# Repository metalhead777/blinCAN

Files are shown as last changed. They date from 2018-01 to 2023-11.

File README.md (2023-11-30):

# blinCAN
A 24 channel LED driver module with CAN bus interface and Arduino-compatible microcontroller. 

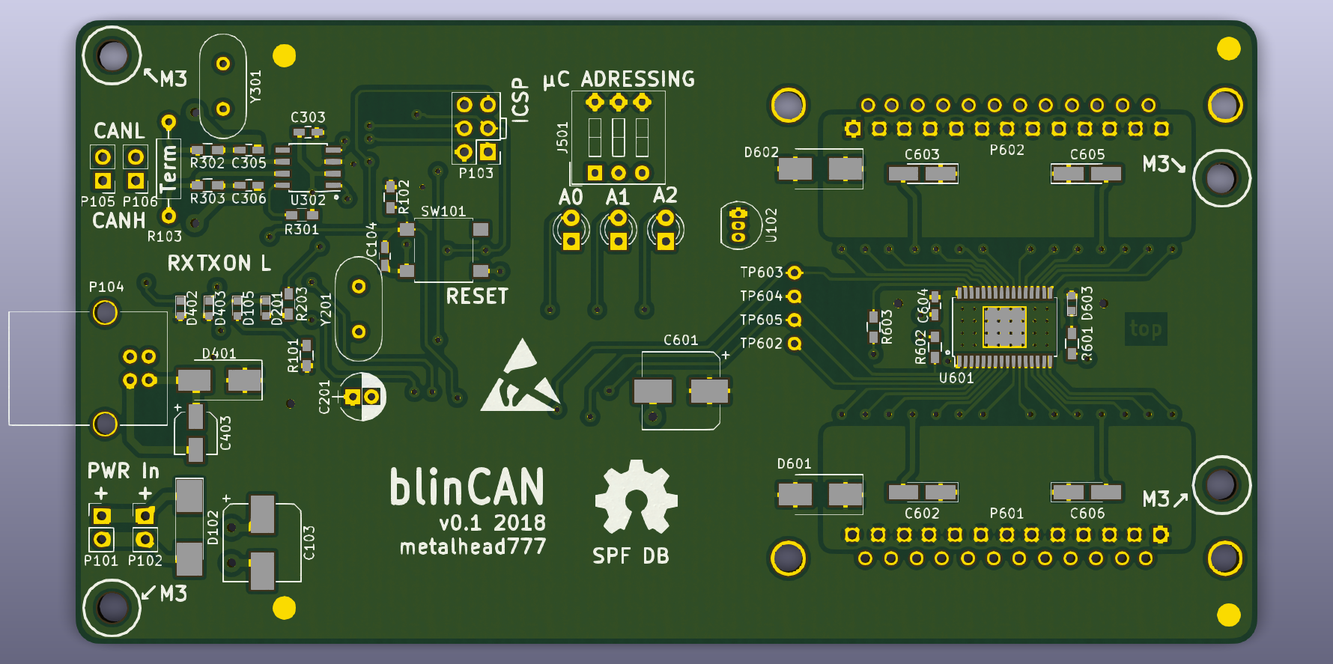
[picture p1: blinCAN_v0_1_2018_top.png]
blinCAN v0.1 2018 top

*blinCAN v0.1 2018 top*

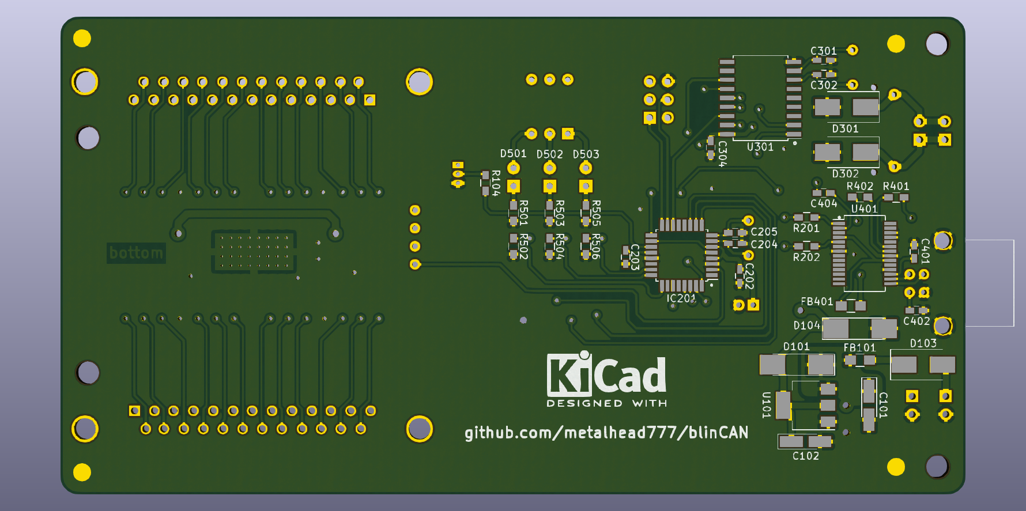
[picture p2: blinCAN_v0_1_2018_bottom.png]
blinCAN v0.1 2018 bottom

*blinCAN v0.1 2018 bottom*

## Function description

The blinCAN is based on a multi-channel power LED driver module developed for the [Desert Eyes project](http://deserteyes.net/). 
It is matched to a small-scale construction prototype dome, which served to test construction and lighting patterns for the full-scale dome. 

This module is built around a TLC5947 PWM LED driver IC, which is connected to an ATmega328 microcontroller. 
For communication, a MCP2551 CAN transceiver and a MCP2515 CAN controller with SPI interface to the microcontroller are utilized. 
A FT232R USB to UART interface has been added to allow programming via USB, once a bootloader is flashed onto the microcontroller. 
For ambient air temperature sensing, a LM35 temperature sensor has been placed near the LED driver IC. 
A DIP switch is used to set a hardware-level address on each device, which also gets indicated by corresponding LEDs.
For easier connection of an already wired LED harness, 25-pin SUB-D connectors are used on the output. 

On the small-scale construction prototype dome, a Raspberry Pi with a CAN bus HAT was used as a host to centrally generate and send lighting patterns to six blinCAN modules via the CAN bus. 
Each blinCAN module had a unique address within the CAN bus, and every LED on the dome was purposely connected to a predefined module output. 
This way, every LED on the dome's shell was distinctly addressable in 3D space. 
An underlying look-up-table in the host's software was used to map each pattern lighting point to an LED. 

### Current stage of development
Currently the blinCAN is in early development state in version 0.1. 
This means, that the hardware is tested and working on a small prototype scale production. 
Long-term testing (temperature, vibration, EMI) has not been performed yet. 
In this state the blinCAN is fit to be used for embedded systems and small-scale lighting projects. 
Any large-scale production is not encouraged, since additional optimization in the hardware layout needs to be done for that. 

A few prototypes have been built and successfully tested prior to releasing this repository. 

### Device commissioning description

#### Device connection

#### Device power requirements

### Device programming

After assembly, the device can only be programmed using an ICSP in-circuit-programmer.
The connector with the reference **P103** serves as ICSP header.
The square pad is ICSP Pin 1 (MISO).

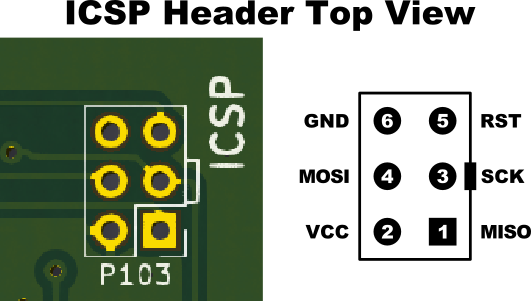
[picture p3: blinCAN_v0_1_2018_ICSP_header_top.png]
P103 ICSP header pin connection


*P103 ICSP header pin connection*

The blinCAN firmware can be flashed directly to the ATmega328P-AU using an In-Series Programmer (ISP).
The reset-button needs to be pressed during microcontroller flashing

For editing the blinCAN firmware or testing any other Arduino-compatible code, the Arduino bootlader needs to be flashed first to the ATmega328P-AU used for the blinCAN.
A tutorial on flashing the Arduino bootloader can be found [here](https://www.arduino.cc/en/tutorial/arduinoISP).
Use the following settings under "Tools" in the Arduino IDE, if you use another Arduino as a flashing device (ISP):

| Parameter | Value |
| --- |:---:|
| Board | "Arduino Nano" |
| Processor | "ATmega328P" |

After flashing the Arduino bootloader, any further programming can be done using the USB type B connector (**P104**) on the blinCAN.

#### Windows

#### Linux

#### MacOS

#### List of successfully tested programming adaptors

### Device communication reference

#### Internal

#### External

#### Addressing scheme

## Currently known bugs and issues
- Reset-button needs to be pressed during microcontroller flashing
- The TLC5947 has a thermal pad, which makes it the only component not solderable by purely using a soldering iron. Using a heatgun to heat the pad from the bottom side, applying solder and then placing the TLC5947 onto it has been done successfully for the prototypes.

## Planned future changes and improvements
- Add Bill of Materials (BOM) for all non-KiCAD users
- Clean up trace routing around TLC5947
- Increase number of hardware address bits
- Change LED output voltage to board input voltage instead of fix 5 V
- Add polyfuse for input overcurrent protection
- Add additional mounting points for Raspberry Pi (host system)

## Open source hardware and software used in this project

### KiCAD

- [KiCAD website](http://kicad.org/)
- Licensed under [GPL Version 3](https://www.gnu.org/licenses/gpl-3.0.html)

### Arduino nano Rev. 3

- [Arduino website](https://www.arduino.cc/)
- [Arduino nano Rev. 3 schematic](https://arduino.cc/en/uploads/Main/Arduino_Nano-Rev3.2-SCH.pdf)
- Licensed under [CC BY-SA 3.0](https://creativecommons.org/licenses/by-sa/3.0/)

### Arduino SparkFun CAN-Bus Shield Rev. 13

- [SparkFun website](https://www.sparkfun.com/)
- [SparkFun CAN-Bus Shield on GitHub](https://github.com/sparkfun/CAN-Bus_Shield/tree/V_H1.3_L5.0.0)
- [SparkFun CAN-Bus Shield Rev. 13 schematic](http://cdn.sparkfun.com/datasheets/Dev/Arduino/Shields/SparkFun_CAN-Bus_Shield_v13a.pdf)
- Licensed under [CC BY-SA 4.0](https://creativecommons.org/licenses/by-sa/4.0/)

## Active contributors to this project

### Firmware programmers

### Library programmers

## License information

This project is open source and licensed under [Creative Commons Attribution Share Alike 4.0](https://creativecommons.org/licenses/by-sa/4.0/).

Please refer to [License.md](License.md) for the full legal text. 
Thanks to [idleberg on GitHub](https://github.com/idleberg/Creative-Commons-Markdown) for the Markdown format. 

The project is distributed as-is. No warranty is given.

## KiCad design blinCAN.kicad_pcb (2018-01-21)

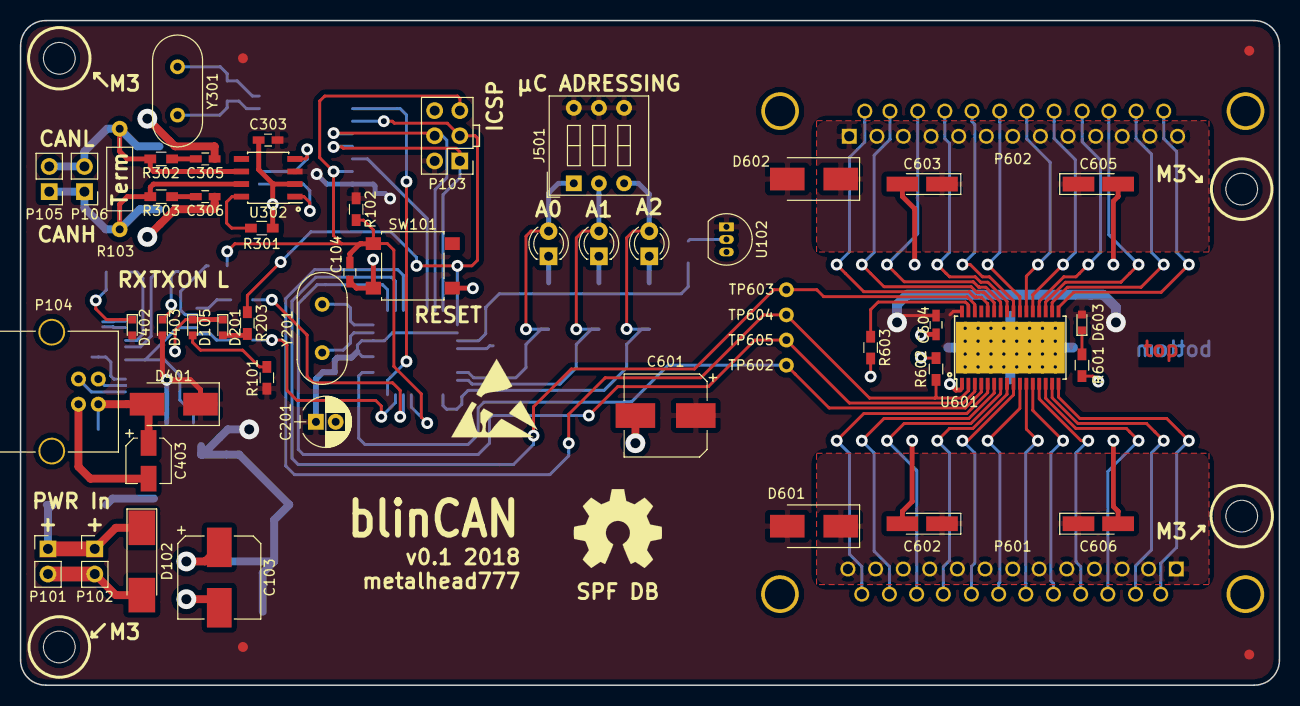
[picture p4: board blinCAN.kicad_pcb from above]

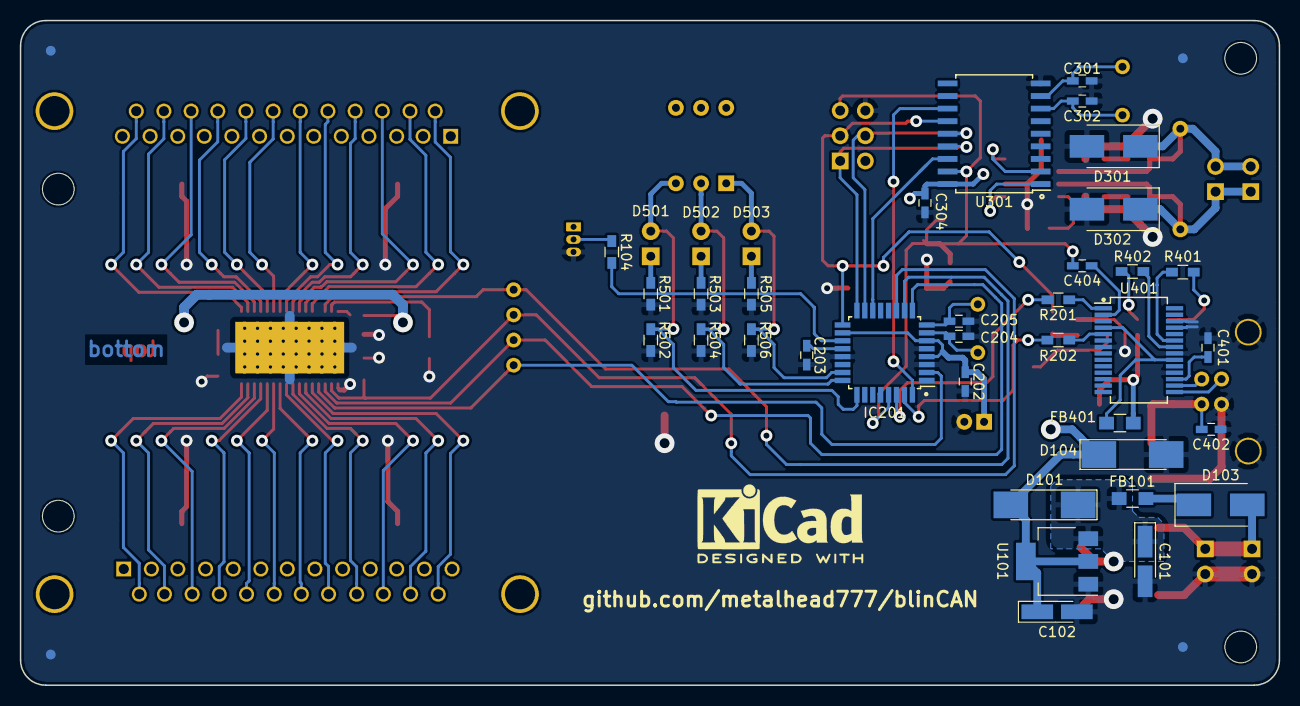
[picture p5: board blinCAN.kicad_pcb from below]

Board: 2 copper layers, 127.1 x 67.1 mm, 88 parts (34 on the bottom side), 79 nets.

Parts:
C101, C102, C602, C603, C605, C606: Tantal 10u/16V; CP_Tantalum_Case-A_EIA-3216-18_Hand
C103: 330u/25V; CP_Elec_8x10.5
C104, C202, C203, C303, C304, C401, C402, C404, C604: 100N; C_0603_HandSoldering
C201: 4.7u/16V; CP_Radial_D5.0mm_P2.00mm
C204, C205, C301, C302: 22P; C_0603_HandSoldering
C305, C306: 560p; C_0603_HandSoldering
C403: 4.7u/16V; CP_Elec_4x5.7
C601: 330u/16V; CP_Elec_8x10.5
D101, D102, D104: 1N 4001 SMD; D_MELF_Handsoldering
D103, D401, D601, D602: MBRS 240 SMD; D_SMB_Handsoldering
D105: LED Blue; LED_0603
D201: LED Orange; LED_0603
D301, D302: P6SMB 27A SMD; D_SMB_Handsoldering
D402: LED Red; LED_0603
D403, D603: LED Green; LED_0603
D501, D502, D503: LED Orange; LED_D3.0mm
FB101, FB401: EMI suppression Filter 30 Ohms; L_0805_HandSoldering
IC201: ATMEGA328P-AU; TQFP-32_7x7mm_Pitch0.8mm
J501: Conn_Address; SW_DIP_x3_W7.62mm_Slide
P101, P102: Conn_PWR_IN; Pin_Header_Straight_1x02_Pitch2.54mm
P103: CONN_ICSP; Pin_Header_Straight_2x03_Pitch2.54mm
P104: USB B; USB_B
P105, P106: Conn_CAN; Pin_Header_Straight_1x02_Pitch2.54mm
P601, P602: D-SUB 25; DB25FC
R101, R203, R401, R402: 330; R_0603_HandSoldering
R102, R104, R201, R202: 1k; R_0603_HandSoldering
R103: 120; R_Axial_DIN0207_L6.3mm_D2.5mm_P10.16mm_Horizontal
R301: 4k7; R_0603_HandSoldering
R302, R303: 100; R_0603_HandSoldering
R501, R503, R505: 130; R_0603_HandSoldering
R502, R504, R506: 10k; R_0603_HandSoldering
R601: 470; R_0603_HandSoldering
R602: 10K; R_0603_HandSoldering
R603: 3K3; R_0603_HandSoldering
SW101: Reset; SW_SPST_B3S-1000
TP602: TEST_DIN; Measurement_Point_Round-TH_Small
TP603: TEST_LAT; Measurement_Point_Round-TH_Small
TP604: TEST_OE; Measurement_Point_Round-TH_Small
TP605: TEST_CLK; Measurement_Point_Round-TH_Small
U101: LD1117S50TR_SOT223; SOT-223-3_TabPin2
U102: LM35DZ; TO-92_Inline_Narrow_Oval
U301: MCP2515-I/SO; SOIC-18W_7.5x11.6mm_Pitch1.27mm
U302: MCP2551-I/SN; SOIC-8_3.9x4.9mm_Pitch1.27mm
U401: FT232R; SSOP-28_5.3x10.2mm_Pitch0.65mm
U601: TLC5947; HTSSOP-32_6.1x11mm_Pitch0.65mm_ThermalPad
Y201, Y301: 16 MHz; Crystal_HC49-U_Vertical

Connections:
0-: P601.25, U601.5
1-: P601.24, U601.6
2-: P601.23, U601.7
3-: P601.22, U601.8
4-: P601.21, U601.9
5-: P601.20, U601.10
6-: P601.19, U601.11
7-: P601.18, U601.12
8-: P601.17, U601.13
9-: P601.16, U601.14
10-: P601.15, U601.15
11-: P601.14, U601.16
12-: P602.25, U601.17
13-: P602.24, U601.18
14-: P602.23, U601.19
15-: P602.22, U601.20
16-: P602.21, U601.21
17-: P602.20, U601.22
18-: P602.19, U601.23
19-: P602.18, U601.24
20-: P602.17, U601.25
21-: P602.16, U601.26
22-: P602.15, U601.27
23-: P602.14, U601.28
+5V: C102.1, C201.1, C202.1, C303.1, C304.1, C601.1, C604.2, D101.2, D104.1, D401.1, D402.2, D403.2, D601.2, D602.2, D603.2, FB401.2, IC201.4, IC201.6, IC201.18, J501.4, J501.5, J501.6, P103.2, R101.1, R102.1, U101.2, U102.1, U301.18, U302.3, U601.32
+12V: C101.1, C103.1, D101.1, FB101.1, U101.3
/Addressing_Switch/Addr0: D503.2, IC201.23, J501.1, R506.2
/Addressing_Switch/Addr1: D502.2, IC201.24, J501.2, R504.2
/Addressing_Switch/Addr2: D501.2, IC201.25, J501.3, R502.2
/CAN_Bus_Driver_Controller//CAN_INT: IC201.32, U301.12
/CAN_Bus_Driver_Controller//CS_CAN: IC201.14, U301.16
/CAN_Bus_Driver_Controller//Reset_CAN: C104.1, C404.2, IC201.29, P103.5, R102.2, SW101.1, U301.17
/CAN_Bus_Driver_Controller/CAN_+: D302.1, P105.1, P106.1, R103.1, R303.1, U302.7
/CAN_Bus_Driver_Controller/CAN_-: D301.1, P105.2, P106.2, R103.2, R302.1, U302.6
/CAN_Bus_Driver_Controller/MISO_CAN: IC201.16, P103.1, U301.15
/CAN_Bus_Driver_Controller/MOSI_CAN: IC201.15, P103.4, U301.14
/Microcontroller/ADC6/A6: IC201.19, R104.2
/Microcontroller/AREF: C203.1, IC201.20
/Microcontroller/PB5/D13/SCKuC: IC201.17, P103.3, R203.1, U301.13
/Microcontroller/PD0/D0/RXuC: R201.1, U401.1
/Microcontroller/PD1/D1/TXuC: R202.1, U401.5
/OE: IC201.11, R602.1, TP604.1, U601.2
/USB_RS232_IC/D+_USB: P104.3, U401.15
/USB_RS232_IC/D-_USB: P104.2, U401.16
/USB_RS232_IC/VCC_USB_Conn: C402.1, C403.1, D401.2, P104.1
CLK: IC201.9, TP605.1, U601.3
DIN: IC201.2, TP602.1, U601.4
GND: C101.2, C102.2, C103.2, C104.2, C201.2, C202.2, C203.2, C204.2, C205.2, C301.2, C302.2, C303.2, C304.2, C305.2, C306.2, C401.2, C402.2, C403.2, C601.2, C602.2, C603.2, C604.1, C605.2, C606.2, D102.2, D104.2, D105.1, D201.1, D301.2, D302.2, IC201.3, IC201.5, IC201.21, P101.2, P102.2, P103.6, P104.4, P104.5, R301.2, R501.1, R502.1, R503.1, R504.1, R505.1, R506.1, R601.2, R602.2, R603.2, SW101.2, U101.1, U102.3, U301.9, U302.2, U401.7, U401.18, U401.21, U401.25, U401.26, U601.1, U601.33
LAT: IC201.10, TP603.1, U601.30
unnamed: C204.1, IC201.7, Y201.1
unnamed: C205.1, IC201.8, Y201.2
unnamed: C301.1, U301.8, Y301.1
unnamed: C302.1, U301.7, Y301.2
unnamed: C305.1, R302.2
unnamed: C306.1, R303.2
unnamed: C401.1, U401.17
unnamed: C404.1, U401.2
unnamed: D102.1, D103.2, P101.1, P102.1
unnamed: D103.1, FB101.2
unnamed: D105.2, R101.2
unnamed: D201.2, R203.2
unnamed: D402.1, R401.1
unnamed: D403.1, R402.1
unnamed: D501.1, R501.2
unnamed: D502.1, R503.2
unnamed: D503.1, R505.2
unnamed: D603.1, R601.1
unnamed: FB401.1, U401.4, U401.20
unnamed: IC201.30, R201.2
unnamed: IC201.31, R202.2
unnamed: R104.1, U102.2
unnamed: R301.1, U302.8
unnamed: R401.2, U401.23
unnamed: R402.2, U401.22
unnamed: R603.1, U601.31
unnamed: U301.1, U302.1
unnamed: U301.2, U302.4
V+_LED_A: C602.1, C606.1, D601.1, P601.1, P601.2, P601.3, P601.4, P601.5, P601.6, P601.7, P601.8, P601.9, P601.10, P601.11, P601.12, P601.13
V+_LED_B: C603.1, C605.1, D602.1, P602.1, P602.2, P602.3, P602.4, P602.5, P602.6, P602.7, P602.8, P602.9, P602.10, P602.11, P602.12, P602.13

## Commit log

2017-11-01 Initial commit: Add KiCAD project files, library files and footprints
    [blinCAN.kicad_pcb, blinCAN.sch, file594A901F.sch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]
2017-11-01 Comment .lib to not interfere with KiCAD.
2017-11-01 Add KiCAD libraries.
2017-11-07 Add symbols to PCB.
    [blinCAN.kicad_pcb]
2017-11-07 Add mounting holes. Moved symbols.
    [blinCAN.kicad_pcb]
2017-11-07 Move symbols.
    [blinCAN.kicad_pcb]
2017-11-07 Add 3D model for TLC5947 to PCB.
    [blinCAN.kicad_pcb]
2017-11-07 Update README.md
    Remove info about DIP switch from future changes and improvements,since it has been implemented.
2018-01-21 Fix some silkscreen misplacements.
    [blinCAN.kicad_pcb]
2018-01-21 Add fiducial marks
    [blinCAN.kicad_pcb]
2018-01-21 Update date on schematics and PCB drawing
    [blinCAN.kicad_pcb, blinCAN.sch, file594A901F.sch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]
2018-01-21 Add GERBER files
    [blinCAN-B.Cu.gbl, blinCAN-B.Mask.gbs, blinCAN-B.SilkS.gbo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]
2019-12-12 Add note about adding BOM in the future. Clean up third-party open source hardware and software used.
2019-12-12 Add PCB renders of current version v0.1.
2019-12-12 Add device programming instructions to README.md.
2021-11-10 Update README.md
    https://forum.kicad.info/t/warning-avoid-all-links-to-kicad-pcb-org-use-kicad-org/31521
